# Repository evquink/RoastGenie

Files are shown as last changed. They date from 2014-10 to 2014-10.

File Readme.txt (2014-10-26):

RoastGenie

This project documents enhancements to the control system in the GeneCafe
Coffee roaster.  It adds PID control, batch label printing, data collection
and processing, and bean mass temperature measurement.

Folders in this repository

* Documentation
Various documentation files covering system design and operation of the
system.

* HeaterInterface
Eagle schematics and board files for hardware that controls the 120v heater.

* PlotGenieSW 
Files required to process the data files from the plot genie using a python
script and gnuplot.

* RoasterInterface
Eagle schematics and board files for hardware that interfaces the Diavolino to
the modified coffee roaster.

* RoastGeniePanel
2-D drawing file for the panel on the RoastGenie Controller.

* RoastGenieSW_Diavolino
Arduino files for the program that runs on the Diavolino for executing primary
roaster control.

* RoastGenieSW_ProTrinket
Arduino files for the program that runs on the ProTrinket for capturing bean
mass temperature.

* RoastGenieSW_RasPi
The Python script that does the data acquisition and file management for the
RoastGenie

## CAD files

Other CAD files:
RoastGeniePanel/RoastGeniePanel.dwg

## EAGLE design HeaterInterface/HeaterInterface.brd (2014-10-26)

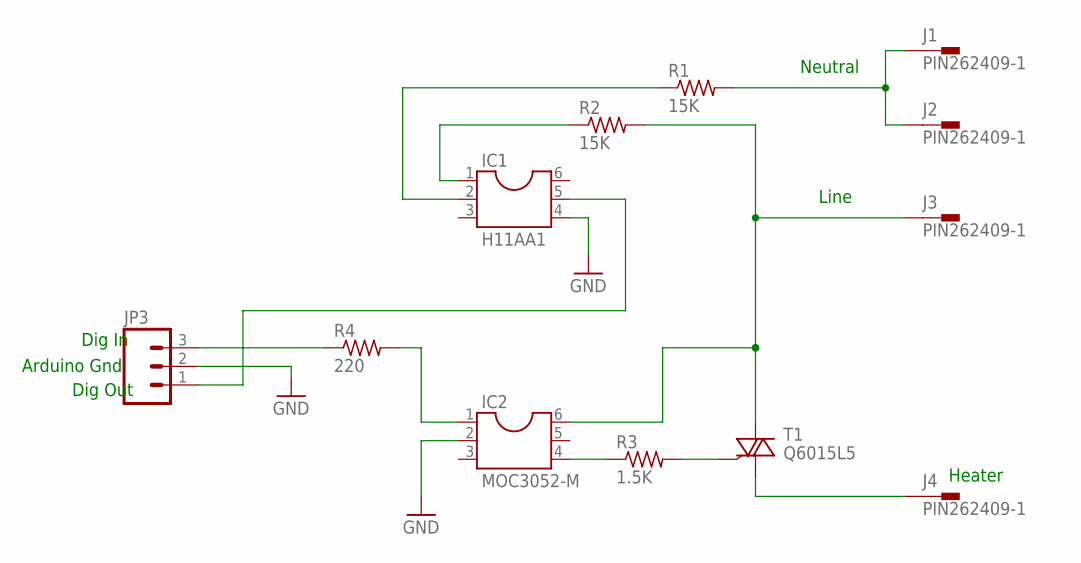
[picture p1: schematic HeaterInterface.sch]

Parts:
IC1: H11AA1; DIL06
IC2: MOC3052-M; DIL06
J1, J2, J3, J4: PIN262409-1; 62409-1
JP3: M03PTH; 1X03
R1, R2: 15K; 0207/10
R3: 1.5K; 0207/10
R4: 220; 0207/10
T1: Q6015L5; TO220BH

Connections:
GND: IC1.4, IC2.2, JP3.2
unnamed: IC1.5, JP3.1
unnamed: IC1.2, R1.1
unnamed: IC1.1, R2.1
unnamed: IC2.6, J3.A1 (1), R2.2, T1.T2 (A2)
unnamed: JP3.3, R4.1
unnamed: IC2.1, R4.2
unnamed: IC2.4, R3.1
unnamed: R3.2, T1.G
unnamed: J4.A1 (1), T1.T1 (A1)
NEUTRAL: J1.A1 (1), J2.A1 (1), R1.2

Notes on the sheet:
Dig Out
Dig In
Arduino Gnd
Neutral
Line
Heater

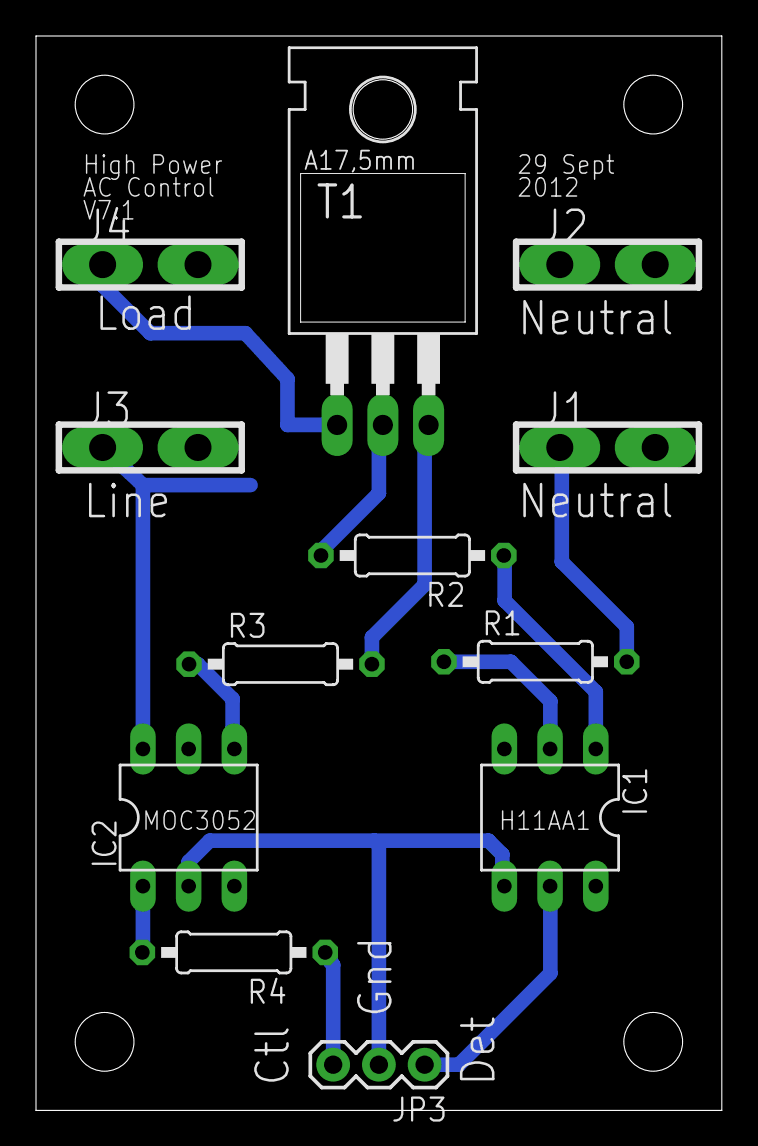
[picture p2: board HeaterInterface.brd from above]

Board: 2 copper layers, 38.1 x 59.7 mm, 12 parts (0 on the bottom side), 11 nets.

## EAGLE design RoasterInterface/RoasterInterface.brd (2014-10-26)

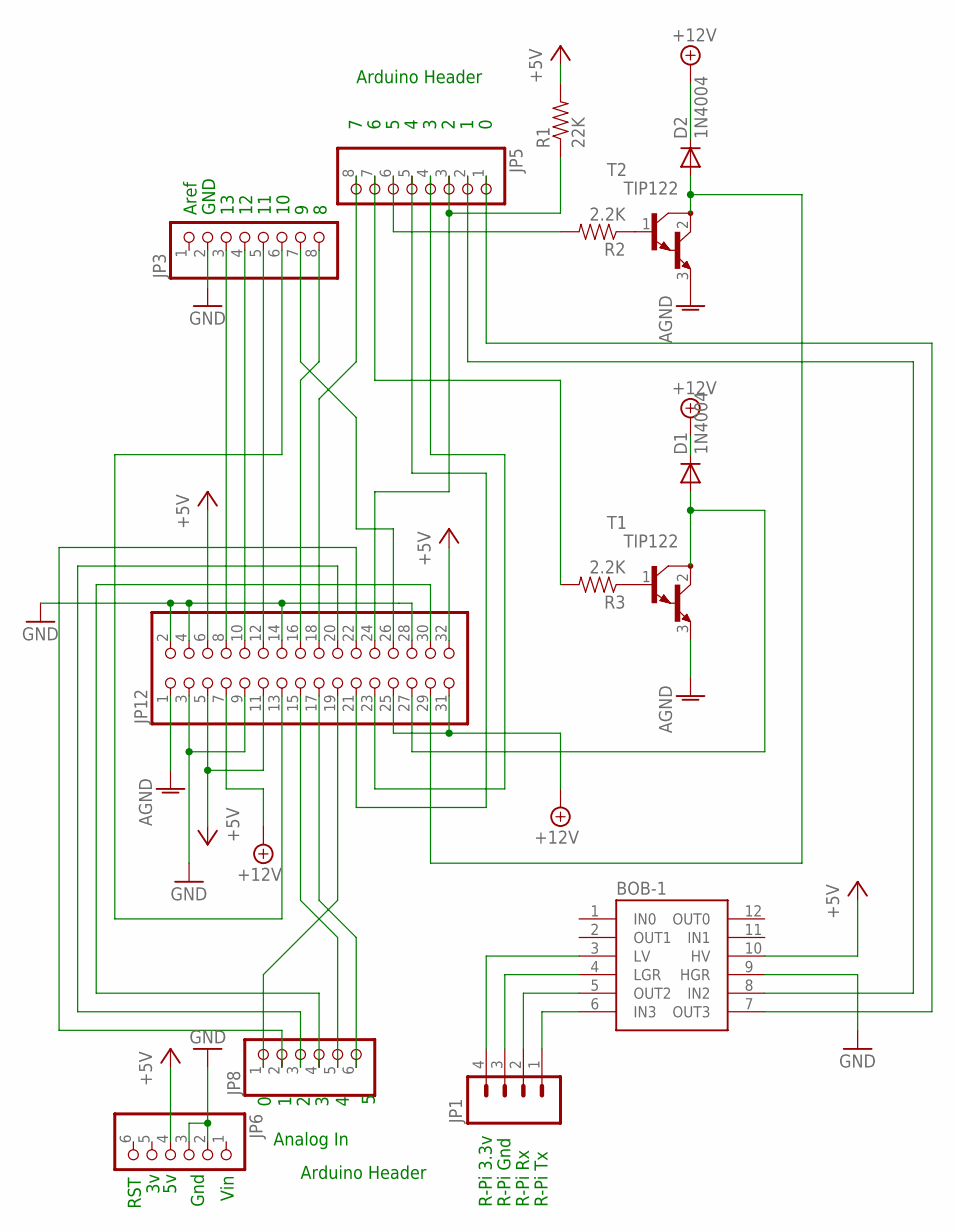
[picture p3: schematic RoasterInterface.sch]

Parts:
BOB-1: BOB-08745DEFAULT; 5X6BOB
D1, D2: 1N4004; DO41-10
JP1: M04LOCK; 1X04_LOCK
JP3, JP5: PINHD-1X8CLEANBIG; 1X08-CLEANBIG
JP6, JP8: PINHD-1X6CB; 1X06-CLEANBIG
JP12: PINHD-2X16; 2X16
R1: 22K; AXIAL-0.4
R2, R3: 2.2K; AXIAL-0.4
T1, T2: TIP122; TO220

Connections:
+5V: BOB-1.10 (HV), JP6.4, JP12.5, JP12.6, JP12.11, JP12.32, R1.P$2 (2)
+12V: D1.C, D2.C, JP12.7, JP12.25, JP12.31
AGND: JP12.1, T1.3 (E), T2.3 (E)
ARD-RX: BOB-1.7 (OUT3), JP5.1
GND: BOB-1.9 (HGR), JP3.2, JP6.2, JP6.3, JP12.2, JP12.3, JP12.4, JP12.9, JP12.14, JP12.28
unnamed: R2.P$1 (1), T2.1 (B)
unnamed: JP3.7, JP12.26
unnamed: JP5.5, JP12.21
unnamed: JP3.8, JP12.16
unnamed: JP5.7, R3.P$2 (2)
unnamed: JP5.8, JP12.18
unnamed: JP3.5, JP12.12
unnamed: JP3.6, JP12.13
unnamed: JP5.6, R2.P$2 (2)
unnamed: JP8.1, JP12.19
unnamed: JP8.5, JP12.15
unnamed: JP3.4, JP12.10
unnamed: R3.P$1 (1), T1.1 (B)
unnamed: JP3.3, JP12.8
unnamed: JP8.6, JP12.17
unnamed: JP8.2, JP12.22
unnamed: JP8.3, JP12.20
unnamed: JP8.4, JP12.30
unnamed: JP5.3, JP12.24, R1.P$1 (1)
unnamed: BOB-1.8 (IN2), JP5.2
unnamed: BOB-1.4 (LGR), JP1.3
unnamed: BOB-1.3 (LV), JP1.4
unnamed: BOB-1.5 (OUT2), JP1.2
unnamed: BOB-1.6 (IN3), JP1.1
unnamed: JP5.4, JP12.23
unnamed: D2.A, JP12.29, T2.2 (C)
unnamed: D1.A, JP12.27, T1.2 (C)

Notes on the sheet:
Arduino Header
Analog In
Vin
Gnd
RST
GND
Aref
R-Pi Gnd
R-Pi 3.3v
R-Pi Rx
R-Pi Tx

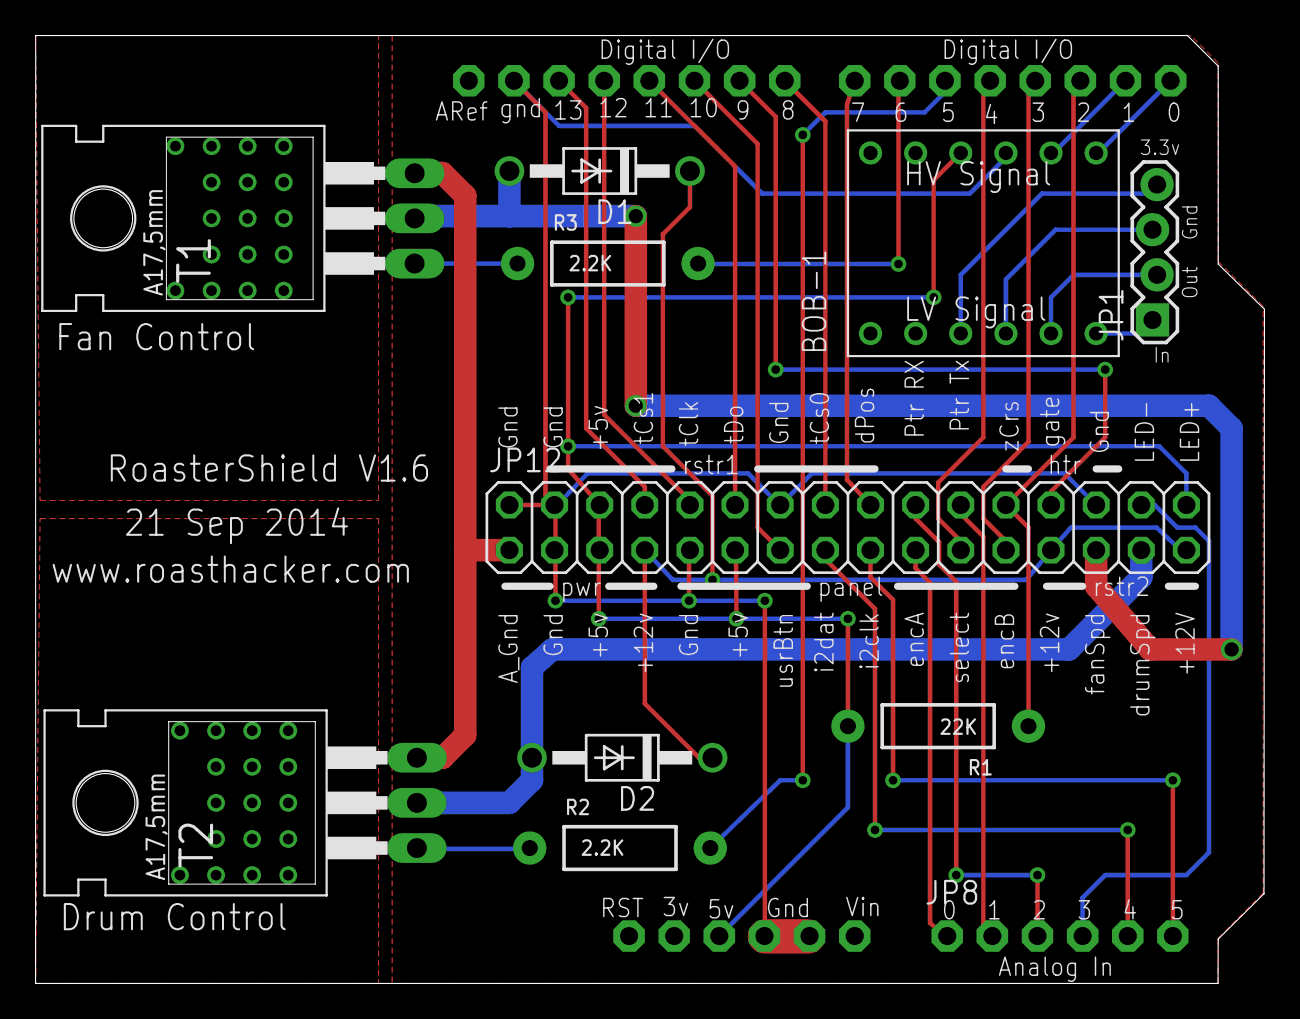
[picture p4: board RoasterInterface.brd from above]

Board: 2 copper layers, 69.2 x 53.4 mm, 14 parts (0 on the bottom side), 32 nets.

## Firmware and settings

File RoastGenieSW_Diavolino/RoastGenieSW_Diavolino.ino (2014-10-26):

const char fileName[] = "RoastGenie_V18";
// Bugs

// debug code needs to be removed

// Version 17.2: Cleanup
// enable interrupt controlling heater _ONLY_ during roast state
// add ability to shutdown raspberry pi
//
// Version 18 for New RoastGenie Hardware
// adds led around user button
// replaces 2 x 16 lcd with 4 x 20 lcd
// Issues:
// make coffee display less "flashy" when running the encoder
// address issue -- arduino does not behave well when raspi link is lost mid process
// compress code
// set up led to come on when active (starting w/green weight entry when not connected)



// Libraries
#include <avr/io.h>
#include <avr/interrupt.h>
#include <avr/programspace.h>
#include <Wire.h>
#include <LiquidTWI2.h>
#include <Encoder.h>
#include <Bounce2.h>
#include <PID_v1.h>
#include <Time.h>
#include <max6675.h>
#include <SoftwareSerial.h>
#include "Adafruit_Thermal.h"

// Pins
#define zeroCross       2
#define encB            3
#define select          4
#define drumSpd         5
#define fanSpd          6                    //was pin 11 in V10
#define drumPos         7
#define tCs1            8                    //was tCs0 in previous versions
#define gate            9
#define userButton      10                   //2nd button pin control panel
#define tD0             11                   //was pin 6 in V10
#define tClk            12
#define tCs0            13                   //was tCs1 in previous versions
#define encA            14                   //AKA A0
#define printer_RX_Pin  15                   // This is the green wire
#define printer_TX_Pin  16                   // This is the yellow wire
#define led             17                   // This is the led around the user button
#define i2dat           18                   //AKA A4
#define i2clk           19                   //AKA A5  

// Constants
#define PULSE           4                    //trigger pusle width for AC control

//Settings
#define T_outSet0      510                   //initial setpoint for outlet temperature
#define T_outSetMin    0
#define T_outSetMax    600
#define T_outCooled    130                   // outlet temperature that must be reached before cooling cycle is automaticlly stopped
#define T_postCrack    490                   // temperature to set back to once first crack has been reached
#define fanSpdPctMin   0                     //minimum allowable fan speed
#define drumSpdPctMin  0                     //minimum allowable drum speed
#define tDrumPeriod    20                    //the number of seconds required for the drum to complete ~2 revolutions.  Used to determine if drum is stopped
#define tShutDown      1500                  //the maximum allowable roast time before forced shutdown
#define tDispDuration  3                     //time (seconds) before display reverts to normal mode



// Flags and flow control variables
boolean   selectState          = HIGH;       //debounced state of the select button
boolean   selectStateFlag      = LOW;        //flag to ensure select button press is relased before next detection
boolean   lastSelectState      = HIGH;
boolean   userButtonState      = HIGH;       //debounced stat of the user button
boolean   userButtonStateFlag  = LOW;         //flag to ensure user button press is released before next detection
boolean   drumPosState         = HIGH;       //debounced state of the drum positon switch
boolean   drumPosLast          = HIGH;       //this is the last state of the drum position switch
boolean   drumState            = LOW;        //this is the state of the roaster drum LOW = stopped, HIGH = turning
boolean   lastRotation         = LOW;        //flag to store signal to turn drum off on next revolution
boolean   lastUserButtonState  = 1;
boolean   subStateToggleLock   = 0;
boolean   subStateChange       = 0;          // high when substate changes
boolean   newSecond            = 0;
boolean   connectedFlag;
int       pgmState             = 0;          //init = 0, load = 5, waiting = 10, roasting = 15, cooling = 20, done = 25
int       subState             = 0;          //tracks sub states within a state
boolean   ctChanged            = LOW;        //keeps track of when coffee type changes during selection process
boolean   userButtonEnabled     = LOW;        //enables / disables user button

//Serial Communication Variables
#define DATABUFFERSIZE           80
char    dataBuffer[DATABUFFERSIZE+1];        //Add 1 for NULL terminator
byte    dataBufferIndex        = 0;          //place to store incoming serial messages
char    startChar              = '{';        //starting character for valid serial message
char    endChar                = '}';        //ending character for valid serial message
boolean storeString            = false;      //flag to indicate valid serial message is coming in
boolean serReady               = 0;          //1 if a valid message is waiting 1 loop only
boolean serBusy                = 0;          //1 if waiting on a reply from the raspi
char    serMsg;                              //place to store command byte of serial message
long    serCnt                 = 0;          //count of loops since serial message was sent - used for timeout
long    serCntLst              = 0;          //used to store loops to get serial communication for debug output
boolean serErr                 = 0;          //place to store serial communication error messages
long    serTO                  = 250;        //how many program loops to wait for a serial response **Make as small as possible**
char    buffer[81]             = "";         //a place to put fomatted data for printing to the lcd

// Counters
int       loopCount            = 0;          //zero for the first loop through a new mode
int       encValueNow          = 0;          //Place to store the value of the parameter
int       encValueOld          = 0;
int       i;                                 //a loop counter
int       j;                                 //a loop counter
int       n;                                 //a loop counter

// Heater, fan, and motor control
double    htrPwrI              = 0;          // Desired heater power (% of max) based on inlet temp
double    htrPwrO              = 0;          // Desired heater power (% of max) based on inlet temp
int       htrPwrPct;                         // The actual heater power desired in % of max available
int       htrPwrCnt;                         // The actual heater power desired in clock counts
int       fanSpdPct            = 100;        //set point for fan speed - percent of max
int       fanSpdCnt;
int       drumSpdPct           = 100;        //set point for drum speed - percent of max
int       drumSpdCnt;


    //Time Variables (tXxxx)
long      tLast;                             //used for once-per-second events    
long      tRoast0              = 0;          //time roasting started
long      tRoast               = 0;          //length of time in roast state
long      tCool0               = 0;          //time cooling started
int       tCool                = 0;          //length of time in cooling state
long      t1stCrack0           = 0;          //time at which first crack occured
int       t1stCrack            = 0;          //time elapsed past 1st crack
long      tInit0               = 0;          //time initialization started
int       tCurrent             = 0;          //time elapsed in current mode
long      tDrumPosLast         = 0;          //the last time the drum position sensor was closed
long      tDispReset           = 0;          //time at which display should reset

    //Temperature Variables T_xxxx, dT_xxxx  
double    T_inSet              = 700;        // Setpoint for the inlet temperature in degrees F
double    T_in                 = 68;         // current inlet temperature
double    T_out                = 68;         // current outlet temperature
double    T_outSet             = T_outSet0;  // Setpoint for the outlet temperature in degrees F

  //Coffee Data
int      coffeeType            = 0;          // index of the type of coffee being roasted
String   coffeeOrigin;                       // origin of selected coffee
String   coffeeFarm;                         // farm from which selected coffee comes
String   dateTime;                           // date and time of roast
int      greenWeight           = 250;        // weight of charge before roasting in grams
int      roastedWeight;                      // weight of charge after roasting in grams
int      invCnt;                             // number of different coffees in the inventory 
double   massLost;

  //PID Constants
double   kpI = 2.5;          // proportional control constant
double   kiI = 0.1;          // integral control constant
double   kdI = 0;            // differential control constant  
double   kpO = 0.9;          // proportional control constant
double   kiO = 0.1;          // integral control constant
double   kdO = 0;            // differential control constant

// This table linearized the relationship between power desired and actual power output
int fcnIn[] = {0,10,20,30,40,50,60,70,80,90,100}; // Desired heater power in percent of maximum available
int fcnOut[] = {500,395,359,331,306,280,254,222,189,155,100};  // Desired heater power in timer count (corresponding to htrpwrPct)

// Object Declarations
MAX6675     tcIn(tClk, tCs0, tD0);
MAX6675     tcOut(tClk, tCs1, tD0);
LiquidTWI2  lcd(0);                        //lcd is called "lcd"
Bounce      selectDb      = Bounce();      //debounce the select button on the encoder
Bounce      drumPosDb     = Bounce();      //debounce the drum position switch 
Bounce      userButtonDb  = Bounce();      //debounce the user button (2nd button on control panel)
Adafruit_Thermal printer(printer_RX_Pin, printer_TX_Pin);
Encoder     myEnc (encB,encA);             //rotary encoder is called "myEnc"
PID         outPID(&T_out, &htrPwrO, &T_outSet, kpO,kiO,kdO, DIRECT);
PID         inPID(&T_in, &htrPwrI, &T_inSet, kpI, kiI, kdI, DIRECT);


void setup(){
  Serial.begin(115200);           //setup serial port for communiction to rasPi
  lcd.setMCPType(LTI_TYPE_MCP23008); 
  lcd.begin(20, 4);               
  printer.begin();                //Setup the thermal printer
  pinMode(select,INPUT);          //This is the select button on the encoder, set the associated pin as an input
  digitalWrite(select,HIGH);      //Set the pull-up resistor on the encoder select button
  selectDb.attach(select);        //Setup for debouncing
  selectDb.interval(5);           //Setup for debouncing
  pinMode(zeroCross, INPUT);      //zero cross detect
  digitalWrite(zeroCross, HIGH);  //enable pull-up resistor
  pinMode(gate, OUTPUT);          //triac gate control
  pinMode(drumSpd, OUTPUT);       //pwm output for drum
  pinMode(fanSpd, OUTPUT);        //pwm output for fan
  pinMode(drumPos, INPUT);        //drum position switch
  digitalWrite(drumPos, HIGH);    //enable pull-up resistor
  drumPosDb.attach(drumPos);      //Setup for debouncing
  drumPosDb.interval(5);          //Setup for debouncing
  pinMode(userButton, INPUT);     //2nd pushbutton on control panel
  digitalWrite(userButton, HIGH); //enable pull-up resistor
  userButtonDb.attach(userButton);//Setup for debouncing
  userButtonDb.interval(5);       //Setup for debouncing
  pinMode (led,OUTPUT);           //LED on user button
  digitalWrite(led, HIGH);        //Turn LED off for starters
  myEnc.write(encValueNow);
  outPID.SetMode(AUTOMATIC);      //initialize PID loop for outlet temp
  inPID.SetMode(AUTOMATIC);       //initialize PID loop for inlet temp
  tLast = now();

  // set up Timer1 
  //(see ATMEGA 328 data sheet pg 134 for more details)
  OCR1A = 505;      //initialize the comparator
  TIMSK1 = 0x03;    //enable comparator A and overflow interrupts
  TCCR1A = 0x00;    //TCCR1A and TCCR1B are control registers 
  TCCR1B = 0x00;    //that configure the behavior of the timer:
                    // *normal operation
                    // *do not control output pins directly
                    // * clock source / 256  
                    

}  

void loop(){
  // do this stuff every single loop
  selectDb.update();                //check to see if the select button has been pressed once per loop
  selectState = selectDb.read();
  drumPosDb.update();               //check to see if the drum positon switch has been activiated once per loop 
  drumPosState = drumPosDb.read();
  userButtonDb.update();            //check to see if the user button has been pressed
  userButtonState = userButtonDb.read();
  subStateChange = 0;               
  outPID.Compute();                 // do PID magic - frequency of calc is controlled by PID code, call on every loop
  inPID.Compute();                  // do PID magic
  getSerialString();                // check for serial messages
  if(userButtonEnabled){
      digitalWrite(led, LOW);        //Turn LED on when button is enabled
  }
  else{
      digitalWrite(led, HIGH);        //Turn LED off when button is disabled
  } 
  
  // This is the temp measurement and control portion, thermal stuff is slow so we only do this once per second.
  // Temp measurement and control is only active in "roasting" and "cooling" modes.
  if (now() > tLast){  //only read thermocouples once per second 
    tLast = now();
    newSecond=1;
    
    ///////////////////////////////////////////////////////////////
    //  PUT DEBUGGING MESSAGES HERE for Once Per Second Updating //
    //////////////////////////////////////////////////////////////  
        
    T_in = tcIn.readFarenheit();    // read inlet thermocouple
    T_out = tcOut.readFarenheit();  // read outlet thermocouple
    htrPwrPct = 100 * min(htrPwrO/255, htrPwrI/255);   //htrPweO and htrPwrI come from PID calcs
    htrPwrCnt = multiMap(htrPwrPct,fcnIn,fcnOut,11);   //determine htrPwrCnt from multiMap interpolation routine
    if(pgmState == 300 || pgmState == 400){ //send roasting data to serial port during roasting and cooling states
      sprintf(buffer,"?D,%05d,%03d,%03d,%03d,%03d,%03d,%05d\n",int(now()-tRoast0),int(T_in),int(T_out),int(T_outSet),int(htrPwrPct),pgmState,t1stCrack);
      Serial.print(buffer);
    }
  }  
  // BOTTOM OF Once-per-second LOOP
  
  //***************************************************************************************
  if (pgmState == 0){  //************************ INITIALIZE ******************************
    if (loopCount == 0){
      loopCount = 1;
      tRoast0=0;
      tRoast=0;
      t1stCrack0=0;
      t1stCrack=0;
      tInit0=now();
      analogWrite(fanSpd, 0);       //fan off (blue LED)
      analogWrite(drumSpd,0);       //drum off (green LED)
    }
    else {
      // *** PROGRAM CODE HERE *** //
      if (1){ // *** Condition to move to next state ***
        pgmState = 100;
        loopCount = 0;
      }
    }      
  }
  //***************************************************************************************  
  if (pgmState == 100){  //**************************** CONNECT ***************************
    if (loopCount == 0){ 
      loopCount = 1;
      connectedFlag = 0;
      lcd.clear();
      lcd.setCursor(3,1);
      lcd.print(fileName);
      lcd.setCursor(3,2);
      lcd.print(F("Connecting...   "));
      lcd.setCursor(3,3);
      lcd.print(F("Free SRAM:"));
      lcd.setCursor(14,3);
      lcd.print(freeRam());
    }
    else {                
      if(serReady){
        if(serMsg == 'c'){
          serReady = 0;
          lcd.setCursor(0,1);
          lcd.print(F("Success...      "));
          connectedFlag = 1;
          pgmState = 110;
          loopCount = 0;
        }
      }
      else if(!serBusy & !connectedFlag){
        if(newSecond){
          Serial.println("?C"); 
          serBusy = 1;
        }
      }
      if (userButtonState == LOW && !userButtonStateFlag){ // failed to connect - move to state 200 on button press
        userButtonStateFlag = HIGH;
        lcd.clear();    
        pgmState = 125;                                 
        loopCount = 0;
      }
    }      
  }
  
  //***************************************************************************************   
  if (pgmState == 105){  //************************* TRIGGER INVENTORY UPDATE *************
    
    if (loopCount == 0){
      loopCount = 1;
    }
    else {
      if(serReady){
        if(serMsg == 'u'){
          serReady=0;
          pgmState = 110;
          loopCount = 0;
        }
      }
      else if(!serBusy){
        Serial.println("?U");
        serBusy = 1;
      }  
    }      
  }  
  
  
  //***************************************************************************************   
  if (pgmState == 110){  //************************* GET COFFEE QTY ***********************
    
    if (loopCount == 0){
      loopCount = 1;
    }
    else {
      if(serReady){
        if(serMsg == 'n'){
          serReady=0;
          invCnt = atoi(dataBuffer);
          pgmState = 120;
          loopCount = 0;
        }
      }
      else if(!serBusy){
        Serial.println("?N");
        serBusy = 1;
      }  
    }      
  }
  //*************************************************************************************** 
  if (pgmState == 120){ //************************** CHOOSE COFFEE ************************ 
    if (loopCount == 0){
      ctChanged = 1;            
      loopCount = 1;
      lcd.clear();
      lcd.setCursor(3,1);
      lcd.print(F("Select Coffee"));
      lcd.setCursor(2,3);
      lcd.print(char(0x7f));
      lcd.setCursor(5,3);
      lcd.print(char(0x7e));      

    }
    else {
      if(serReady){
        int curPos1;
        if(serMsg == 'i'){
          serReady=0;
          if(ctChanged){
            lcd.setCursor(0,0);
            lcd.print(F("                    "));
            lcd.setCursor(0,1);
            lcd.print(F("                    "));
            lcd.setCursor(int((20-strlen(dataBuffer))/2),1);
            lcd.print(dataBuffer);
            Serial.print("?O,");            //now get the origin
            Serial.println(coffeeType);
            serBusy = 1;
          }

        }
        if(serMsg == 'o'){
          serReady=0;
          lcd.setCursor(0,0);
          lcd.print(F("                    "));
          lcd.setCursor(int((20-strlen(dataBuffer))/2),0);
          lcd.print(dataBuffer);

        }
      }
      if(int delta = checkEnc()){        // do this only when encoder changes 
        ctChanged = 1;
        coffeeType = coffeeType + delta;
        lcd.setCursor(14,3);
        lcd.print(F("SELECT"));
        lcd.setCursor(2,3);
        lcd.print(char(0x7f));
        lcd.setCursor(5,3);
        lcd.print(char(0x7e));       
        
        
        
        
        userButtonEnabled = 1;            //enable userButton
        if (coffeeType > invCnt -1){
          coffeeType = invCnt -1;
          ctChanged = 0;                  //went past end of list -- coffee type did not change
          lcd.setCursor(5,3);
          lcd.print(" ");
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

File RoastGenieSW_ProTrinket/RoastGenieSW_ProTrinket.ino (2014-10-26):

//BeanMassProbe

/*
The MIT License (MIT)

Copyright (c) [2014] [Evan Graham]

Permission is hereby granted, free of charge, to any person obtaining a copy of this software and associated documentation files (the "Software"), to deal in the Software without restriction, including without limitation the rights to use, copy, modify, merge, publish, distribute, sublicense, and/or sell copies of the Software, and to permit persons to whom the Software is furnished to do so, subject to the following conditions:

The above copyright notice and this permission notice shall be included in all copies or substantial portions of the Software.

THE SOFTWARE IS PROVIDED "AS IS", WITHOUT WARRANTY OF ANY KIND, EXPRESS OR IMPLIED, INCLUDING BUT NOT LIMITED TO THE WARRANTIES OF MERCHANTABILITY, FITNESS FOR A PARTICULAR PURPOSE AND NONINFRINGEMENT. IN NO EVENT SHALL THE AUTHORS OR COPYRIGHT HOLDERS BE LIABLE FOR ANY CLAIM, DAMAGES OR OTHER LIABILITY, WHETHER IN AN ACTION OF CONTRACT, TORT OR OTHERWISE, ARISING FROM, OUT OF OR IN CONNECTION WITH THE SOFTWARE OR THE USE OR OTHER DEALINGS IN THE SOFTWARE.
*/



#include <SPI.h>
#include "Adafruit_MAX31855.h"

#define         RATE        2                                    //rate = # of times/second a temperature reading is taken

#define         DO          5
#define         CS          4
#define         CLK         3


Adafruit_MAX31855 thermocouple(CLK, CS, DO);

int t_delay = int(1000/RATE);                                     // this is the number of thousandths of a second between temp readings
int TmaxLoopCount=0;                                              // # of measurements since Tmax was set
int TminLoopCount=0;                                              // # of measurements since Tmin was set

double Tmin;                                                      // best estimate of minumum temperature (this is bean mass temp)
double Tmax;                                                      // best estimate of maximum temperature (this is environmental temp)
double Tnow;                                                      // current thermocouple reading (t=0)
double Tlast;                                                     // last thermocouple reading (t=-1)
double T_dif_now;                                                 // temp difference between most recent readings(t = 0 and = -1)
double T_dif_last;                                                // temp difference between previous two readings (t = -1 and t = -2)

char    buffer[81]             = "";                              //a place to put fomatted data for printing 

long interval = 500;                                              // interval at which to read thermocouple (milliseocnds)
unsigned long currentMillis = millis(); 
long previousMillis = 0;                                          // will store last time thermocouple was read
int inByte = 0;                                                   // incoming serial byte

void setup() {
  Serial.begin(9600);
  // wait for MAX chip to stabilize
  delay(500);
  Tmin = thermocouple.readFarenheit();
  Tlast = Tnow = Tmax = Tmin;
  T_dif_now = 0;
  T_dif_last = 0;
}

void loop() {
  currentMillis = millis();
  if(currentMillis - previousMillis > interval) {
     previousMillis = currentMillis;   
     Tnow = thermocouple.readFarenheit();
     TminLoopCount ++;
     TmaxLoopCount ++;
     T_dif_now = Tnow - Tlast;
    
     if (T_dif_now >= 0.0 && T_dif_last < 0.0 && TminLoopCount > 1){    // this is a local minimum
       Tmin = Tlast;                                                    // best estimate of environmental temp
       TminLoopCount = 0;                                               // reset loop counter
     }
   
     if (T_dif_now <= 0.0 && T_dif_last > 0.0 && TmaxLoopCount > 1){    // this is a local maximum
       Tmax = Tlast;                                                    // best estimate of bean mass temp
       TmaxLoopCount = 0;                                               // reset loop counter
     }
  
     Tlast = Tnow;
     T_dif_last = T_dif_now;
  }
  
  if (Serial.available() > 0) {                                        // send temp when character is received
    inByte = Serial.read();
    if(inByte == '?'){
      sprintf(buffer,"%03d, %03d, %03d",int(Tnow),int(Tmin),int(Tmax));
      Serial.println(buffer);
    }
  }

}

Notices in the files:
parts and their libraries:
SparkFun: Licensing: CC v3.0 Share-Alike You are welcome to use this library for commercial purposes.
